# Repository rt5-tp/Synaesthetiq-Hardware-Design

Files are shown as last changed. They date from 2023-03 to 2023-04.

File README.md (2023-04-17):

# SynaesthetiQ Hardware

SynaesthetiQ's hardware centre's around a pair of flexible LED Matrices which have been wrapped around a 3D printed core, palced on top of this core is a 30W RGB COB LED.

Matrcies on Core
Big LED Demo

## AuxBoard

SynaesthetiQ has an Auxillary Board which provides power to both of the matrices, the big led, Raspberry Pi 4B and a fan for cooling. This board is detailed in the [AuxBoard KiCAD project](./AuxBoard/). This board distributes power provided by an ATX power supply while also providing Back Powering protection from the RPI and polyfuse protection to each of the four areas of supply on the board. AuxBoard provides levelshifting from the 3.3v of the RPI's logic to the 5v of the matrices and the big LED.

### Schematic
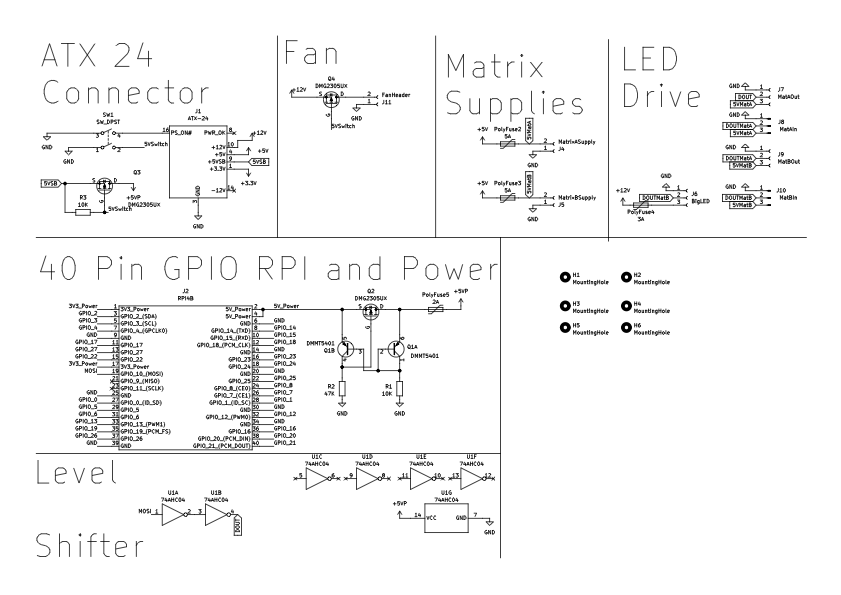
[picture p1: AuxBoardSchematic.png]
AuxBoard Schematic

### PCB Layout
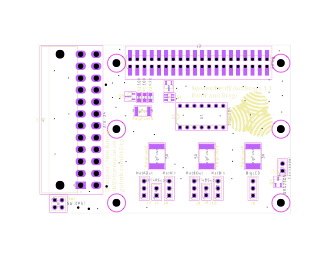
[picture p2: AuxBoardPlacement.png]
PCB Layout

### Final PCB's
The most recent PCB for the project.
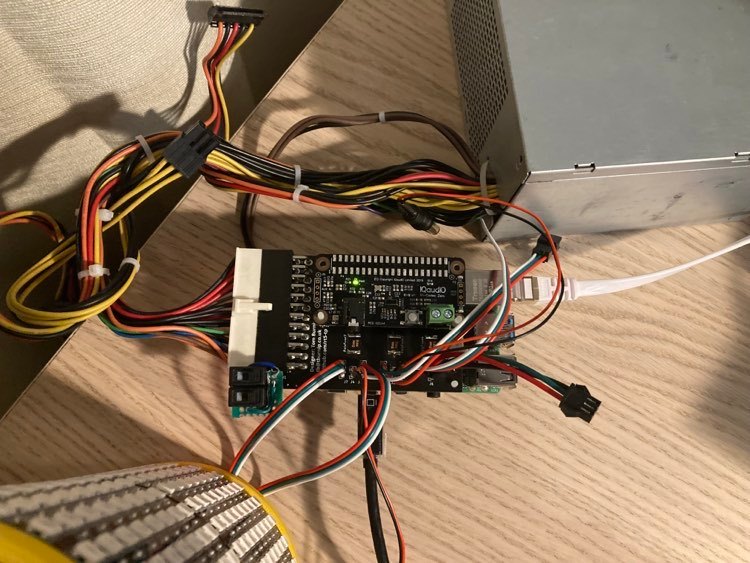
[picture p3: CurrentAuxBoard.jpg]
Current PCB


Below is two of the eventual three PCBs made for the project.
Final PCB's

## PMOS Switch

Exists to test the functionality of the PMOS Switch circuit being used.

## ZVD Sim

Is a KiCAD project which simulates the Back powering protection built into the SynaesthetiQ AuxBoard.

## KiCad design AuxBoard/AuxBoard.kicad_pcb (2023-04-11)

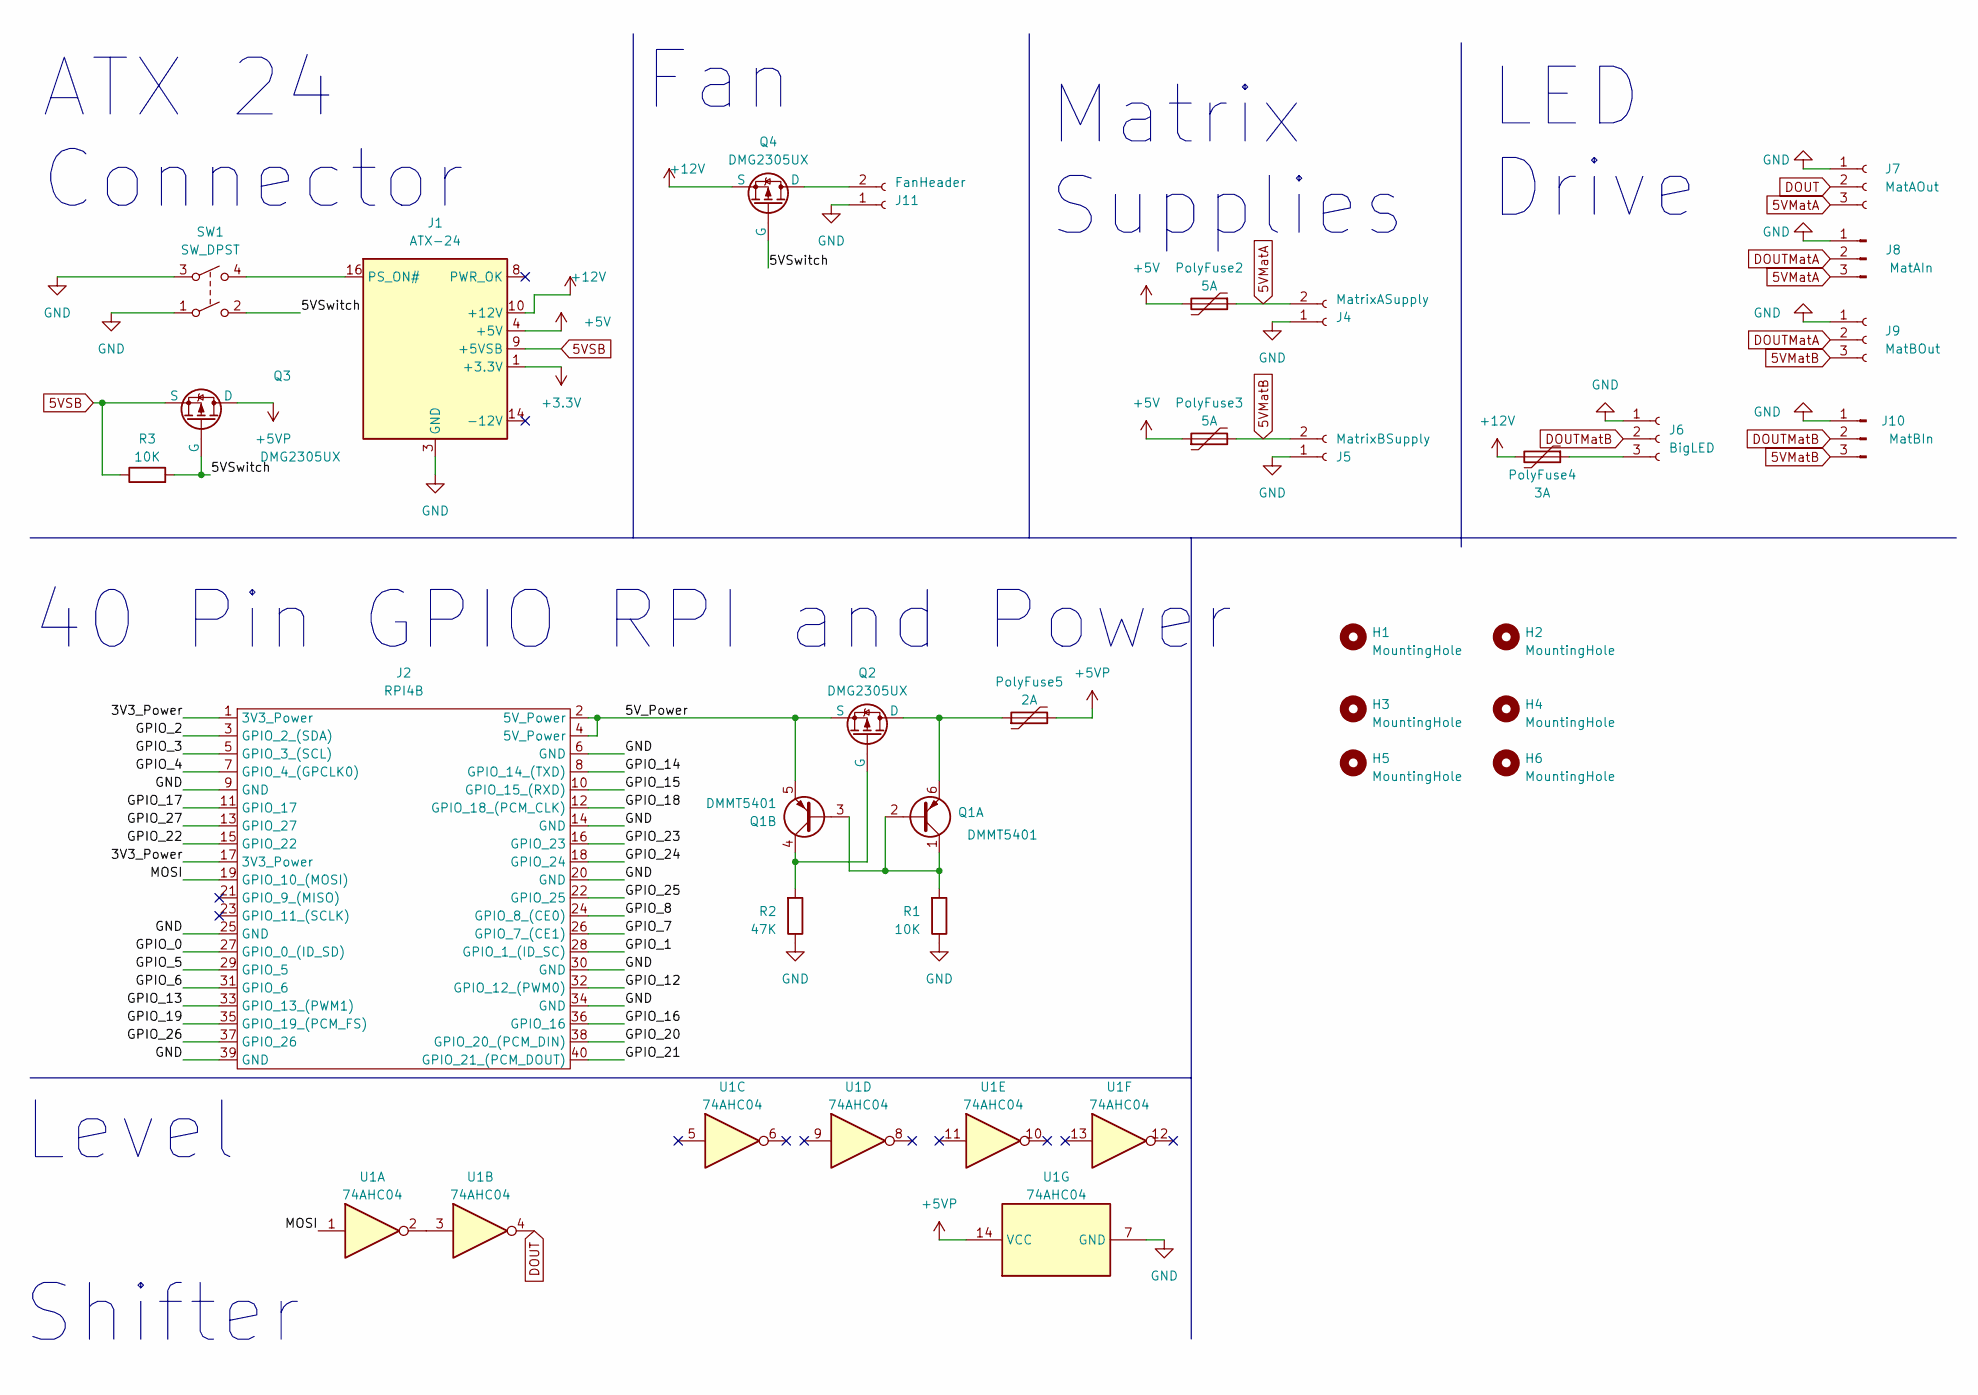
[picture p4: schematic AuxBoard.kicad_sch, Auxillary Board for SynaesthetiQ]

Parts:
H1, H2, H3, H4, H5, H6: MountingHole; MountingHole_2.75mm_RPI_HAT
J1: ATX-24; Molex_Mini-Fit_Jr_5569-24A2_2x12_P4.20mm_Horizontal
J2: RPI4B; PI Header Passthrough
J4: MatrixASupply; PinSocket_1x02_P2.54mm_Vertical
J5: MatrixBSupply; PinSocket_1x02_P2.54mm_Vertical
J6: BigLED; PinSocket_1x03_P2.54mm_Vertical
J7: MatAOut; PinSocket_1x03_P2.54mm_Vertical
J8: MatAIn; PinSocket_1x03_P2.54mm_Vertical
J9: MatBOut; PinSocket_1x03_P2.54mm_Vertical
J10: MatBIn; PinSocket_1x03_P2.54mm_Vertical
J11: FanHeader; PinSocket_1x02_P2.54mm_Vertical
PolyFuse2, PolyFuse3: 5A; Fuse_2920_7451Metric_Pad2.10x5.45mm_HandSolder
PolyFuse4: 3A; Fuse_2920_7451Metric_Pad2.10x5.45mm_HandSolder
PolyFuse5: 2A; Fuse_1812_4532Metric_Pad1.30x3.40mm_HandSolder
Q1: DMMT5401; SOT-23-6
Q2, Q3, Q4: DMG2305UX; SOT-23-3
R1, R3: 10K; R_0805_2012Metric_Pad1.20x1.40mm_HandSolder
R2: 47K; R_0805_2012Metric_Pad1.20x1.40mm_HandSolder
SW1: SW_DPST; PinHeader_2x02_P2.54mm_Vertical
U1: 74AHC04; DIP-14_W7.62mm

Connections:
5VMatA: J4.2, J7.3, J8.3, PolyFuse2.1
5VMatB: J5.2, J9.3, J10.3, PolyFuse3.2
5VSB: J1.9 (+5VSB), Q3.2 (S), R3.1
+3.3V: J1.1 (+3.3V), J1.2 (+3.3V), J1.12 (+3.3V), J1.13 (+3.3V)
+5V: J1.4 (+5V), J1.6 (+5V), J1.21 (+5V), J1.22 (+5V), J1.23 (+5V), PolyFuse2.2, PolyFuse3.1
+5VP: PolyFuse5.2, Q3.3 (D), U1.14 (VCC)
+12V: J1.10 (+12V), J1.11 (+12V), PolyFuse4.2, Q4.2 (S)
/3V3_Power: J2.1 (3V3_Power), J2.17 (3V3_Power)
/5VSwitch: Q3.1 (G), Q4.1 (G), R3.2, SW1.2
/5V_Power: J2.2 (5V_Power), J2.4 (5V_Power), Q1.5 (E2), Q2.2 (S)
/GPIO_0: J2.27 (GPIO_0_(ID_SD))
/GPIO_1: J2.28 (GPIO_1_(ID_SC))
/GPIO_2: J2.3 (GPIO_2_(SDA))
/GPIO_3: J2.5 (GPIO_3_(SCL))
/GPIO_4: J2.7 (GPIO_4_(GPCLK0))
/GPIO_5: J2.29 (GPIO_5)
/GPIO_6: J2.31 (GPIO_6)
/GPIO_7: J2.26 (GPIO_7_(CE1))
/GPIO_8: J2.24 (GPIO_8_(CE0))
/GPIO_12: J2.32 (GPIO_12_(PWM0))
/GPIO_13: J2.33 (GPIO_13_(PWM1))
/GPIO_14: J2.8 (GPIO_14_(TXD))
/GPIO_15: J2.10 (GPIO_15_(RXD))
/GPIO_16: J2.36 (GPIO_16)
/GPIO_17: J2.11 (GPIO_17)
/GPIO_18: J2.12 (GPIO_18_(PCM_CLK))
/GPIO_19: J2.35 (GPIO_19_(PCM_FS))
/GPIO_20: J2.38 (GPIO_20_(PCM_DIN))
/GPIO_21: J2.40 (GPIO_21_(PCM_DOUT))
/GPIO_22: J2.15 (GPIO_22)
/GPIO_23: J2.16 (GPIO_23)
/GPIO_24: J2.18 (GPIO_24)
/GPIO_25: J2.22 (GPIO_25)
/GPIO_26: J2.37 (GPIO_26)
/GPIO_27: J2.13 (GPIO_27)
/MOSI: J2.19 (GPIO_10_(MOSI)), U1.1
DOUT: J7.2, U1.4
DOUTMatA: J8.2, J9.2
DOUTMatB: J6.2, J10.2
GND: J1.3 (GND), J1.5 (GND), J1.7 (GND), J1.15 (GND), J1.17 (GND), J1.18 (GND), J1.19 (GND), J1.24 (GND), J2.6 (GND), J2.9 (GND), J2.14 (GND), J2.20 (GND), J2.25 (GND), J2.30 (GND), J2.34 (GND), J2.39 (GND), J4.1, J5.1, J6.1, J7.1, J8.1, J9.1, J10.1, J11.1, R1.1, R2.1, SW1.1, SW1.3, U1.7 (GND)
unnamed: J1.16 (PS_ON#), SW1.4
unnamed: J6.3, PolyFuse4.1
unnamed: J11.2, Q4.3 (D)
unnamed: Q1.1 (C1), Q1.2 (B1), Q1.3 (B2), R1.2
unnamed: PolyFuse5.1, Q1.6 (E1), Q2.3 (D)
unnamed: Q1.4 (C2), Q2.1 (G), R2.2
unnamed: U1.2, U1.3

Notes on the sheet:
ATX 24 Connector
Fan
Level Shifter
LED Drive
40 Pin GPIO RPI and Power
Matrix Supplies

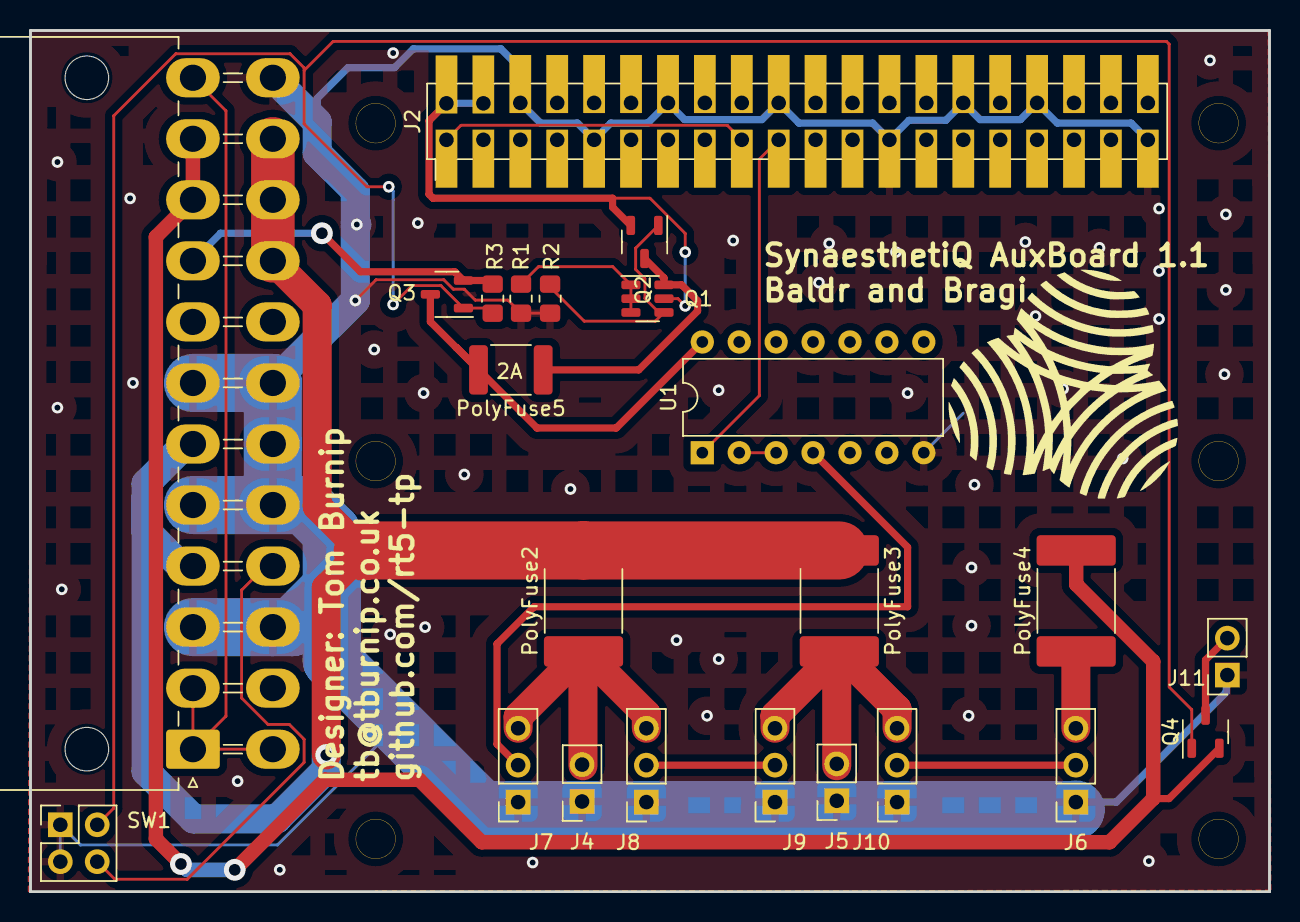
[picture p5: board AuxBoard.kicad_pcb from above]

Board: 2 copper layers, 85.2 x 59.2 mm, 29 parts (0 on the bottom side), 22 nets.

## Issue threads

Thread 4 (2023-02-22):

Test Physical Prototype

TBurnip, 2023-02-22:

TBurnip, 2023-02-22:
https://vm.tiktok.com/ZMYSgBax3/

TBurnip, 2023-02-22:
[Matrix Test Code used](https://github.com/rt5-tp/LED_Matrix_Tests)

Closed 2023-02-22.

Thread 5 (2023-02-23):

Automatic PDF Export from Ki-Cad

TBurnip, 2023-02-23:
This should help others view work performed on the schematic and PCB designs.

TBurnip, 2023-02-26:
Worked on basic PDF Schematic Export. Need to workout a more convenient way to surface them.

Closed 2023-03-07.

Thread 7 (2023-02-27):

Consider Heat management!

TBurnip, 2023-02-27:
- Add a fan header to AuxBoard
- Consider how to add headsinks to both the PI and the LED
- Consider Fan location and direction of air flow.

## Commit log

2023-02-18 Intial Daughter Board Design
    [AuxBoard.kicad_pcb, AuxBoard.kicad_sch]
2023-02-18 Added headers to handle comms with Matrices and Big LED
    [AuxBoard.kicad_pcb, AuxBoard.kicad_sch]
2023-02-22 Power Distro Changes
    [AuxBoard.kicad_pcb, AuxBoard.kicad_sch]
2023-02-24 Adding Basic CI for kicad
2023-02-26 Added seccond GPIO
    [AuxBoard.kicad_pcb, AuxBoard.kicad_sch]
2023-02-26 Draft Schematic Finished. Added ZVD and Changed to polyfuses
    [AuxBoard.kicad_pcb, AuxBoard.kicad_sch]
2023-02-27 Added fan header and mosfet control for PI power supply
    [AuxBoard.kicad_pcb, AuxBoard.kicad_sch]
2023-03-06 Simulated Ideal Diode to check functionality. Swaped Tristate buffer for hex inverter. Swapped to passthrough footprint.
    [AuxBoard.kicad_pcb, AuxBoard.kicad_sch, ZVD.kicad_sch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]
2023-03-06 Final PCB Layout
    [AuxBoard.kicad_pcb, AuxBoard.kicad_sch]
2023-03-06 Filled GND Net. Fixed most 3d elements
    [AuxBoard.kicad_pcb]
2023-03-06 Added Silkscreen
    [AuxBoard.kicad_pcb]
2023-03-07 Gerbers for PCB. Fixed RPI Header Mistake. PCB will need bodge.
    [AuxBoard-B_Cu.gbl, AuxBoard-B_Mask.gbs, AuxBoard-B_Paste.gbp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]
2023-03-22 Fixing Header Orientation
    [AuxBoard.kicad_pcb, AuxBoard.kicad_sch]
2023-04-01 Updates to the Aux Board PCB
    [AuxBoard.kicad_pcb, AuxBoard.kicad_sch, PMOSSwitch.kicad_pcb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]
2023-04-17 Current AuxBoard and README
2023-04-17 Added info on other KiCAD Projects
2023-04-17 Added a picture of the most recent PCB to the readme.
